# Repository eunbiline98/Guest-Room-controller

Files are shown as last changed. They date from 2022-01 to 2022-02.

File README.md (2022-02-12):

# Guest-Room-controller
dev Load Controller Guest-Room-controller Mqtt protocol home assistant support

# Guest-Room-controller V.1
- SoC board esp32
- 6 Or 8 Group Relay Omron M2YN
- Support Led Stip adressing WS2812/WS2811
- Home Assistant Integrated Or Stand Alone
# 8 Zone guest room controller
# 6 Zone guest room controller V1

# Guest-Room-controller V.2
- SoC board esp32
- 5 Group Relay SPDT 
- 3 Group Dimmer 0-10V
-  Stand Alone ( Next Home Assistant Integrated )
# guest room controller V2

# Smart Switch Momentary
https://github.com/eunbiline98/Smart-Switch-Momentary-

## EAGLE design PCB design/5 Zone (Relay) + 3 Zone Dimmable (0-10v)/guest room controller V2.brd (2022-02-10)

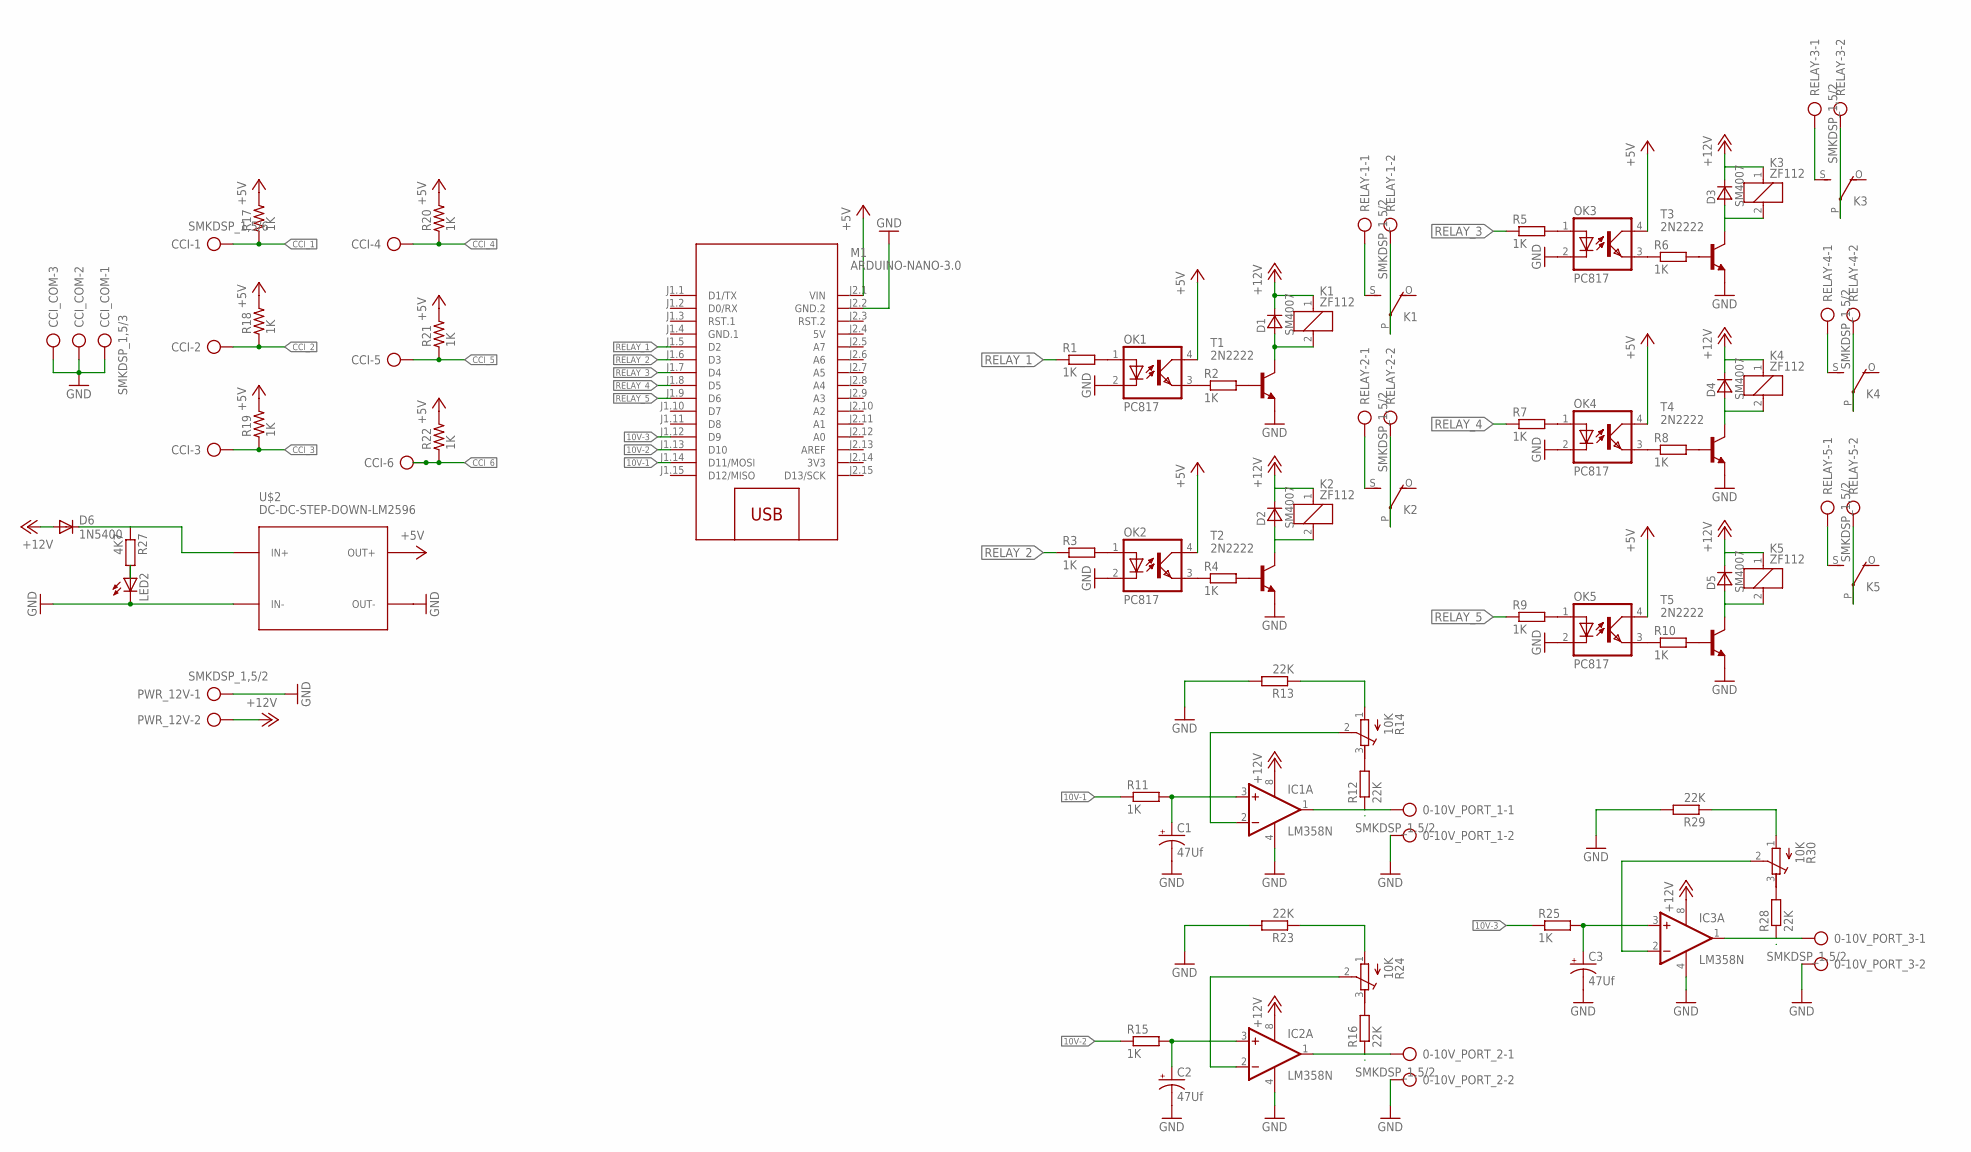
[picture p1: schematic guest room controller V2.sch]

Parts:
0-10V_PORT_1, 0-10V_PORT_2, 0-10V_PORT_3: SMKDSP_1,5/2
C1, C2, C3: 47Uf; E2,5-6
CCI: SMKDSP_1,5/6
CCI_COM: SMKDSP_1,5/3
D1, D2, D3, D4, D5: SM4007; MELF-MLL41
D6: 1N5400; DO201-15
IC1, IC2, IC3: LM358N; DIL08
K1, K2, K3, K4, K5: ZF112
LED2: LED3MM
M1: ARDUINO-NANO-3.0
OK1, OK2, OK3, OK4, OK5: PC817; DIL04
PWR_12V: SMKDSP_1,5/2
R1, R2, R3, R4, R5, R6, R7, R8, R9, R10, R11, R15, R25: 1K; 0207/10
R12, R13, R16, R23, R28, R29: 22K; 0207/10
R14, R24, R30: 10K; RTRIM64P
R17, R18, R19, R20, R21, R22: 1K; R1206
R27: 4K7; 0207/10
RELAY-1, RELAY-2, RELAY-3, RELAY-4, RELAY-5: SMKDSP_1,5/2
T1, T2, T3, T4, T5: 2N2222; TO18
U$2: DC-DC-STEP-DOWN-LM2596

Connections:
3V3: M1.J2.14 (3V3)
5V: M1.J2.4 (5V)
10V-1: M1.J1.14 (D11/MOSI), R11.1
10V-2: M1.J1.13 (D10), R15.1
10V-3: M1.J1.12 (D9), R25.1
+5V: M1.J2.1 (VIN), OK1.4 (COL), OK2.4 (COL), OK3.4 (COL), OK4.4 (COL), OK5.4 (COL), R17.2, R18.2, R19.2, R20.2, R21.2, R22.2, U$2.OUT+
+12V: D1.C, D2.C, D3.C, D4.C, D5.C, D6.A, IC1.8 (V+), IC2.8 (V+), IC3.8 (V+), K1.1, K2.1, K3.1, K4.1, K5.1, PWR_12V.2
CCI_1: CCI.1, R17.1
CCI_2: CCI.2, R18.1
CCI_3: CCI.3, R19.1
CCI_4: CCI.4, R20.1
CCI_5: CCI.5, R21.1
CCI_6: CCI.6, R22.1
GND: 0-10V_PORT_1.2, 0-10V_PORT_2.2, 0-10V_PORT_3.2, C1.-, C2.-, C3.-, CCI_COM.1, CCI_COM.2, CCI_COM.3, IC1.4 (V-), IC2.4 (V-), IC3.4 (V-), LED2.K (C), M1.J2.2 (GND.2), OK1.2 (C), OK2.2 (C), OK3.2 (C), OK4.2 (C), OK5.2 (C), PWR_12V.1, R13.2, R23.2, R29.2, T1.1 (E), T2.1 (E), T3.1 (E), T4.1 (E), T5.1 (E), U$2.IN-, U$2.OUT-
GND.1: M1.J1.4 (GND.1)
unnamed: OK1.3 (EMIT), R2.1
unnamed: R2.2, T1.2 (B)
unnamed: D1.A, K1.2, T1.3 (C)
unnamed: OK2.3 (EMIT), R4.1
unnamed: R4.2, T2.2 (B)
unnamed: D2.A, K2.2, T2.3 (C)
unnamed: OK3.3 (EMIT), R6.1
unnamed: R6.2, T3.2 (B)
unnamed: D3.A, K3.2, T3.3 (C)
unnamed: OK4.3 (EMIT), R8.1
unnamed: R8.2, T4.2 (B)
unnamed: D4.A, K4.2, T4.3 (C)
unnamed: OK5.3 (EMIT), R10.1
unnamed: R10.2, T5.2 (B)
unnamed: D5.A, K5.2, T5.3 (C)
unnamed: K1.S, RELAY-1.1
unnamed: LED2.A, R27.2
unnamed: C1.+, IC1.3 (+IN), R11.2
unnamed: 0-10V_PORT_1.1, IC1.1 (OUT), R12.1
unnamed: R12.2, R14.3 (E)
unnamed: IC1.2 (-IN), R14.2 (S)
unnamed: R13.1, R14.1 (A)
unnamed: C2.+, IC2.3 (+IN), R15.2
unnamed: OK1.1 (A), R1.2
unnamed: OK2.1 (A), R3.2
unnamed: OK3.1 (A), R5.2
unnamed: OK4.1 (A), R7.2
unnamed: OK5.1 (A), R9.2
unnamed: 0-10V_PORT_2.1, IC2.1 (OUT), R16.1
unnamed: D6.C, R27.1, U$2.IN+
unnamed: K1.P, RELAY-1.2
unnamed: R16.2, R24.3 (E)
unnamed: K2.S, RELAY-2.1
unnamed: IC2.2 (-IN), R24.2 (S)
unnamed: R23.1, R24.1 (A)
unnamed: C3.+, IC3.3 (+IN), R25.2
unnamed: 0-10V_PORT_3.1, IC3.1 (OUT), R28.1
unnamed: R28.2, R30.3 (E)
unnamed: IC3.2 (-IN), R30.2 (S)
unnamed: R29.1, R30.1 (A)
unnamed: K2.P, RELAY-2.2
unnamed: K3.S, RELAY-3.1
unnamed: K3.P, RELAY-3.2
unnamed: K4.P, RELAY-4.2
unnamed: K4.S, RELAY-4.1
unnamed: K5.P, RELAY-5.2
unnamed: K5.S, RELAY-5.1
RELAY_1: M1.J1.5 (D2), R1.1
RELAY_2: M1.J1.6 (D3), R3.1
RELAY_3: M1.J1.7 (D4), R5.1
RELAY_4: M1.J1.8 (D5), R7.1
RELAY_5: M1.J1.9 (D6), R9.1

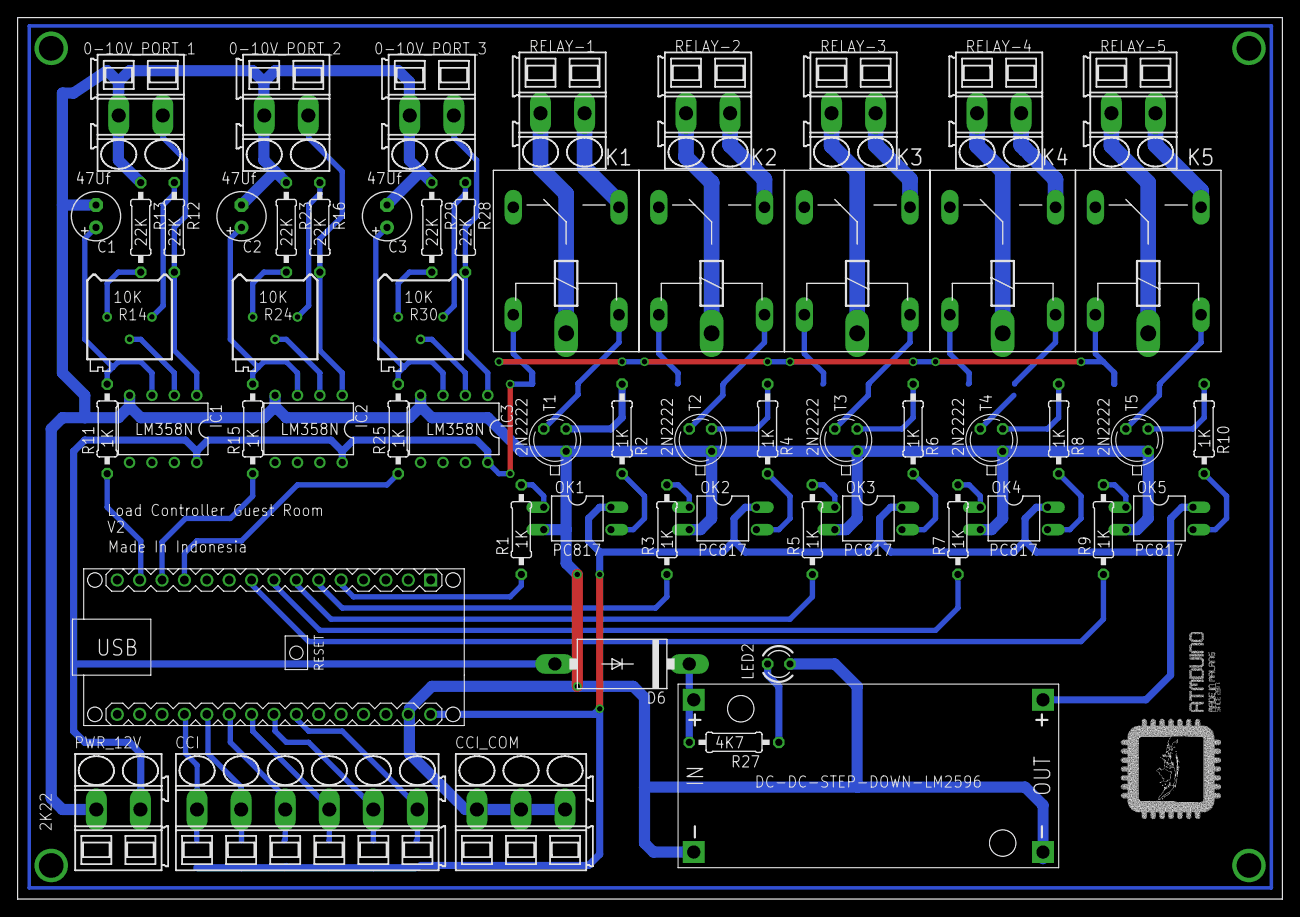
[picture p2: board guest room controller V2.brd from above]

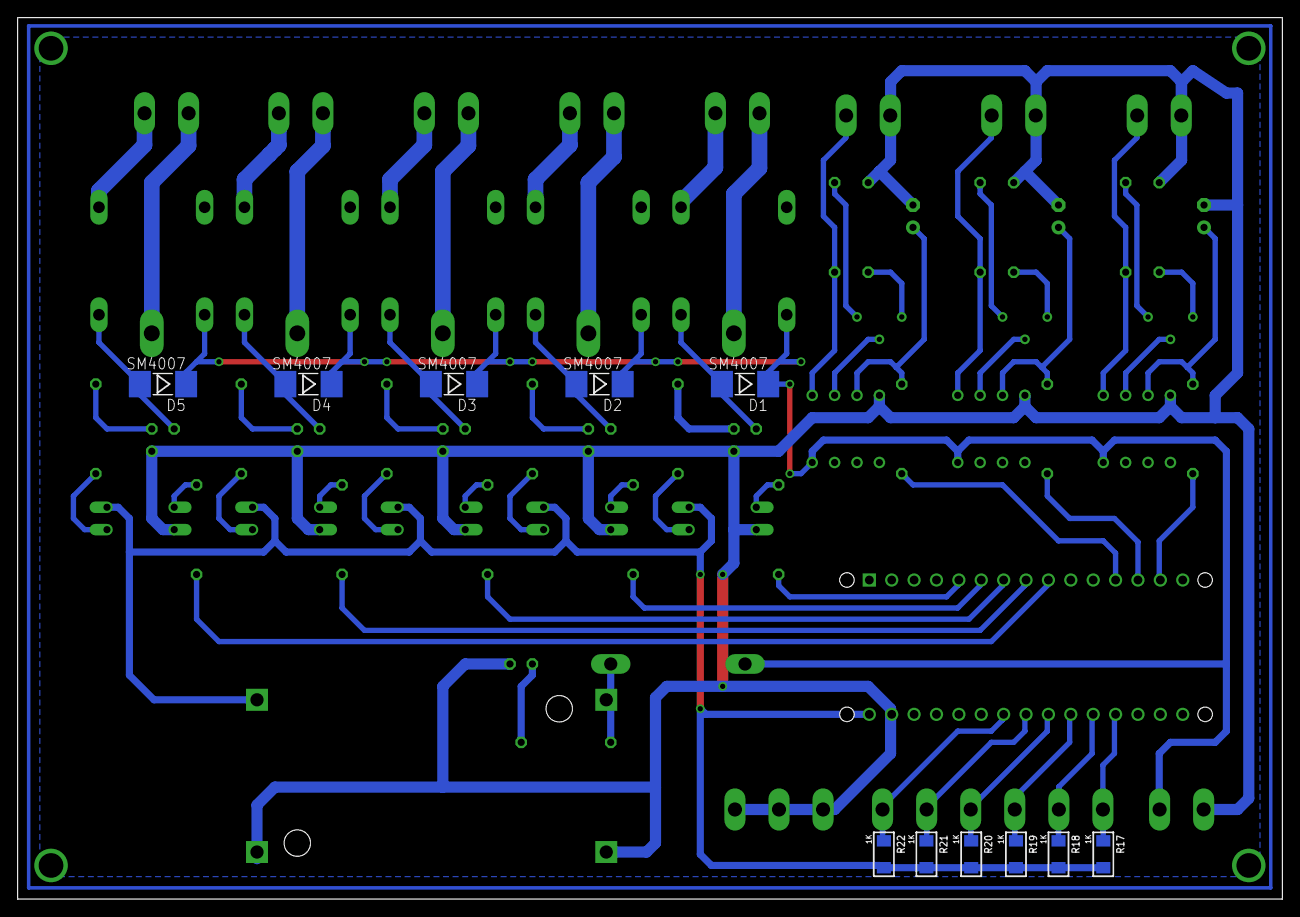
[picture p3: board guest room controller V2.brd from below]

Board: 2 copper layers, 143.5 x 100.0 mm, 70 parts (11 on the bottom side), 64 nets.

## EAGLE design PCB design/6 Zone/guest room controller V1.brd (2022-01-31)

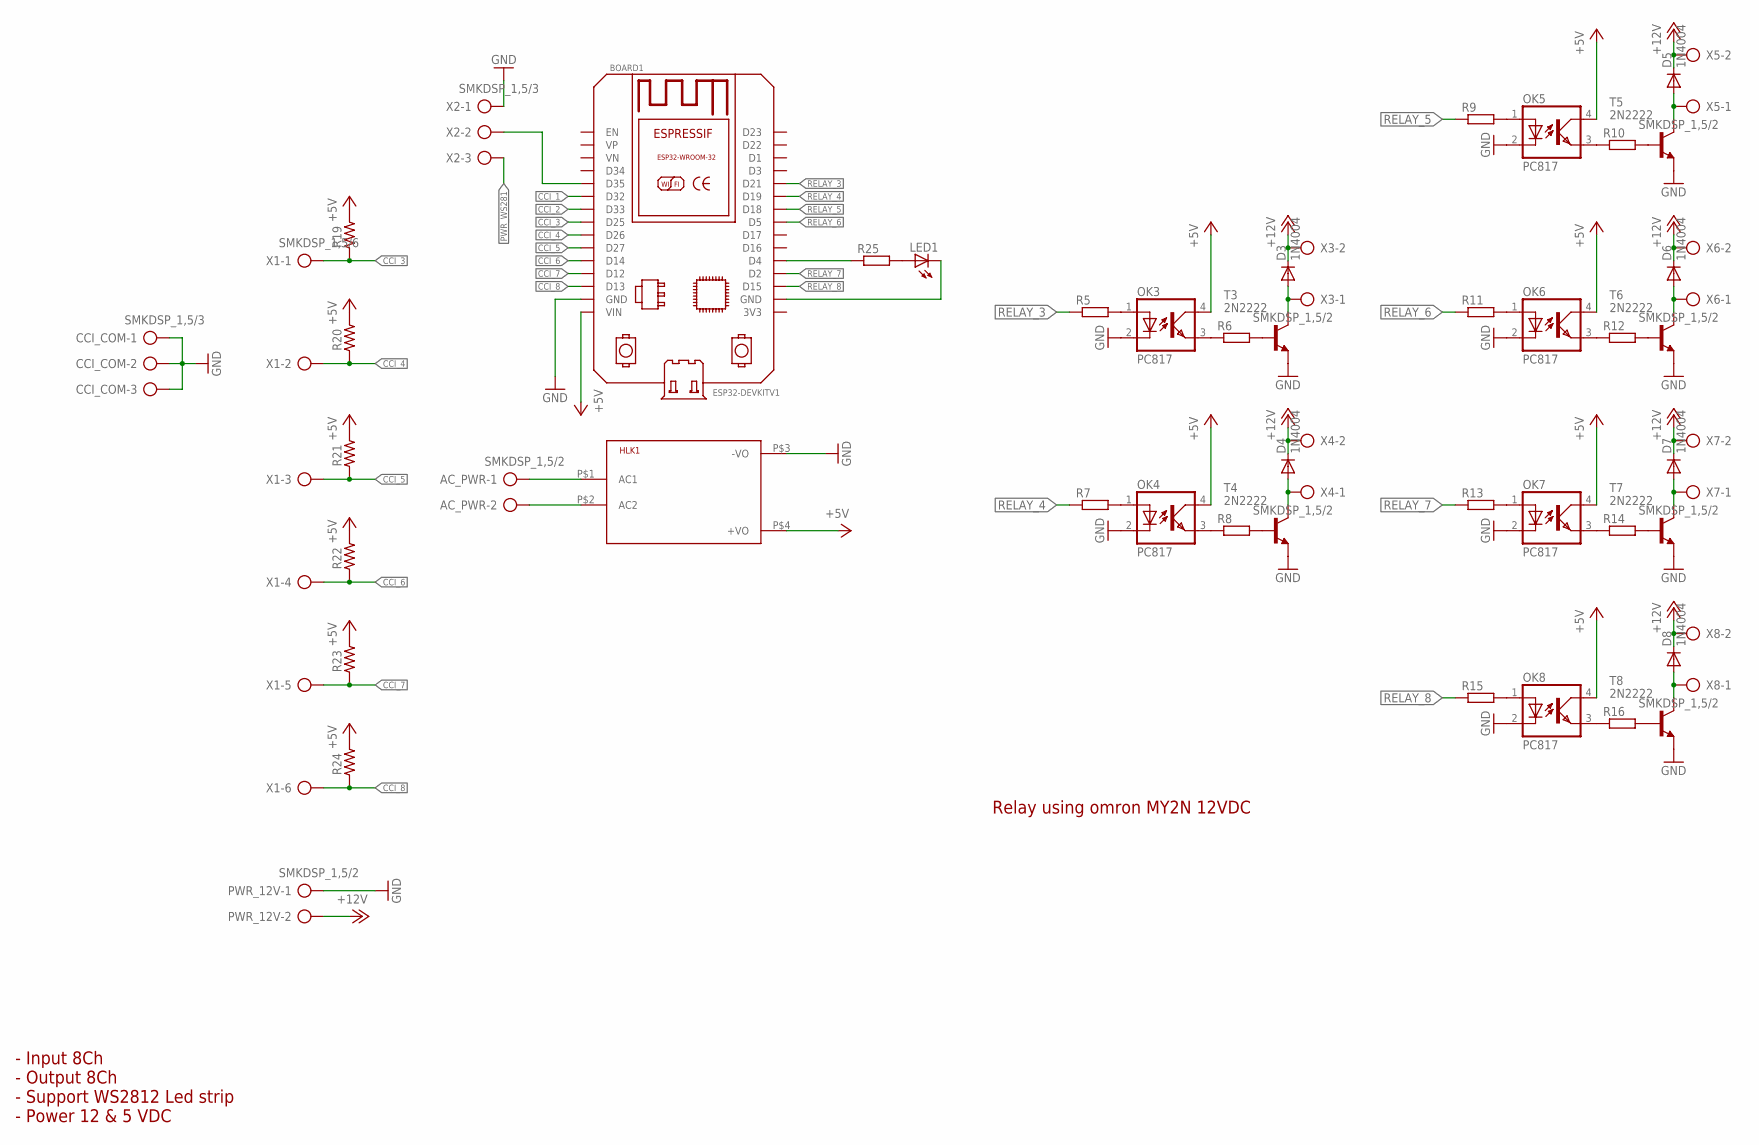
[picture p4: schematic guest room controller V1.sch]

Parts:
AC_PWR: SMKDSP_1,5/2
BOARD1: ESP32DEVKITV1; ESP32-DEVKITV1
CCI_COM: SMKDSP_1,5/3
D3, D4, D5, D6, D7, D8: 1N4004; DO41-10
HLK1: HLK-PM013W; HLK-PM01
LED1: LED3MM
OK3, OK4, OK5, OK6, OK7, OK8: PC817; DIL04
PWR_12V: SMKDSP_1,5/2
R5, R6, R7, R8, R9, R10, R11, R12, R13, R14, R15, R16, R25: R-EU_0207/10; 0207/10
R19, R20, R21, R22, R23, R24: R_1206; R1206
T3, T4, T5, T6, T7, T8: 2N2222; TO18
X1: SMKDSP_1,5/6
X2: SMKDSP_1,5/3
X3, X4, X5, X6, X7, X8: SMKDSP_1,5/2

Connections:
+5V: BOARD1.VIN, HLK1.P$4 (+VO), OK3.4 (COL), OK4.4 (COL), OK5.4 (COL), OK6.4 (COL), OK7.4 (COL), OK8.4 (COL), R19.2, R20.2, R21.2, R22.2, R23.2, R24.2
+12V: D3.C, D4.C, D5.C, D6.C, D7.C, D8.C, PWR_12V.2, X3.2, X4.2, X5.2, X6.2, X7.2, X8.2
CCI_1: BOARD1.D32
CCI_2: BOARD1.D33
CCI_3: BOARD1.D25, R19.1, X1.1
CCI_4: BOARD1.D26, R20.1, X1.2
CCI_5: BOARD1.D27, R21.1, X1.3
CCI_6: BOARD1.D14, R22.1, X1.4
CCI_7: BOARD1.D12, R23.1, X1.5
CCI_8: BOARD1.D13, R24.1, X1.6
GND: BOARD1.GND, CCI_COM.1, CCI_COM.2, CCI_COM.3, HLK1.P$3 (-VO), OK3.2 (C), OK4.2 (C), OK5.2 (C), OK6.2 (C), OK7.2 (C), OK8.2 (C), PWR_12V.1, T3.1 (E), T4.1 (E), T5.1 (E), T6.1 (E), T7.1 (E), T8.1 (E), X2.1
unnamed: OK3.3 (EMIT), R6.1
unnamed: R6.2, T3.2 (B)
unnamed: D3.A, T3.3 (C), X3.1
unnamed: OK4.3 (EMIT), R8.1
unnamed: R8.2, T4.2 (B)
unnamed: D4.A, T4.3 (C), X4.1
unnamed: OK5.3 (EMIT), R10.1
unnamed: R10.2, T5.2 (B)
unnamed: D5.A, T5.3 (C), X5.1
unnamed: OK6.3 (EMIT), R12.1
unnamed: R12.2, T6.2 (B)
unnamed: D6.A, T6.3 (C), X6.1
unnamed: OK7.3 (EMIT), R14.1
unnamed: R14.2, T7.2 (B)
unnamed: D7.A, T7.3 (C), X7.1
unnamed: OK8.3 (EMIT), R16.1
unnamed: R16.2, T8.2 (B)
unnamed: D8.A, T8.3 (C), X8.1
unnamed: AC_PWR.1, HLK1.P$1 (AC1)
unnamed: OK3.1 (A), R5.2
unnamed: OK4.1 (A), R7.2
unnamed: OK5.1 (A), R9.2
unnamed: OK6.1 (A), R11.2
unnamed: OK7.1 (A), R13.2
unnamed: OK8.1 (A), R15.2
unnamed: BOARD1.D4, R25.1
unnamed: LED1.A, R25.2
unnamed: BOARD1.GND@1 (GND), LED1.K (C)
unnamed: BOARD1.D35, X2.2
unnamed: AC_PWR.2, HLK1.P$2 (AC2)
PWR_WS281: X2.3
RELAY_3: BOARD1.D21, R5.1
RELAY_4: BOARD1.D19, R7.1
RELAY_5: BOARD1.D18, R9.1
RELAY_6: BOARD1.D5, R11.1
RELAY_7: BOARD1.D2, R13.1
RELAY_8: BOARD1.D15, R15.1

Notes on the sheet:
- Input 8Ch - Output 8Ch - Support WS2812 Led strip - Power 12 & 5 VDC
Relay using omron MY2N 12VDC

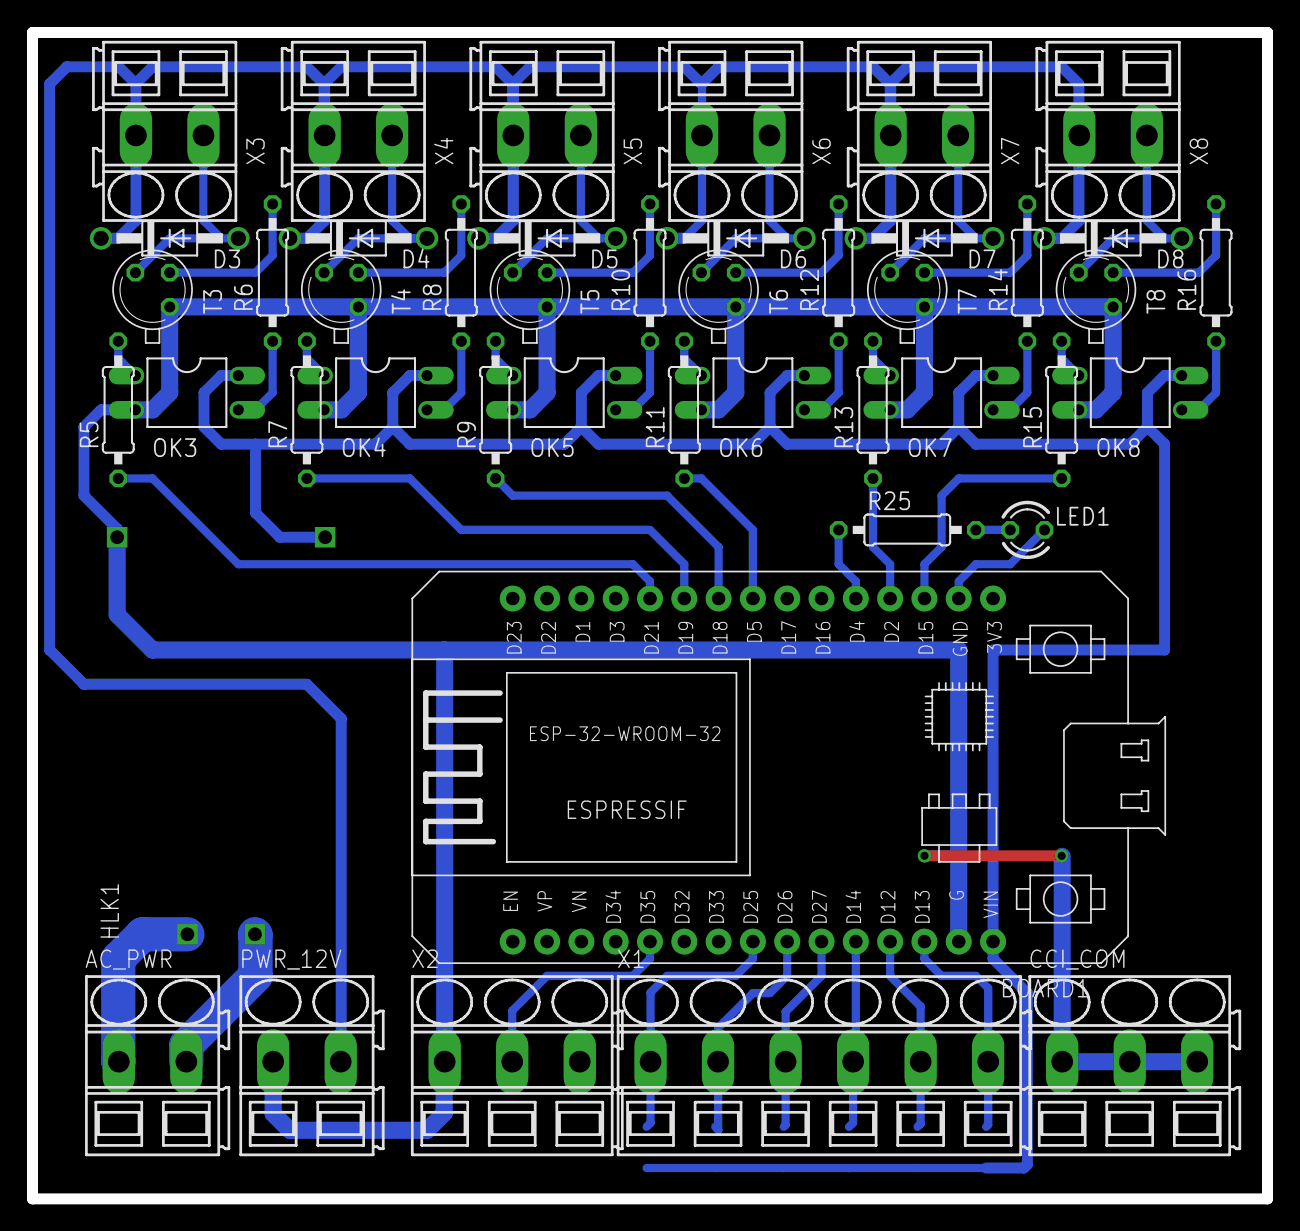
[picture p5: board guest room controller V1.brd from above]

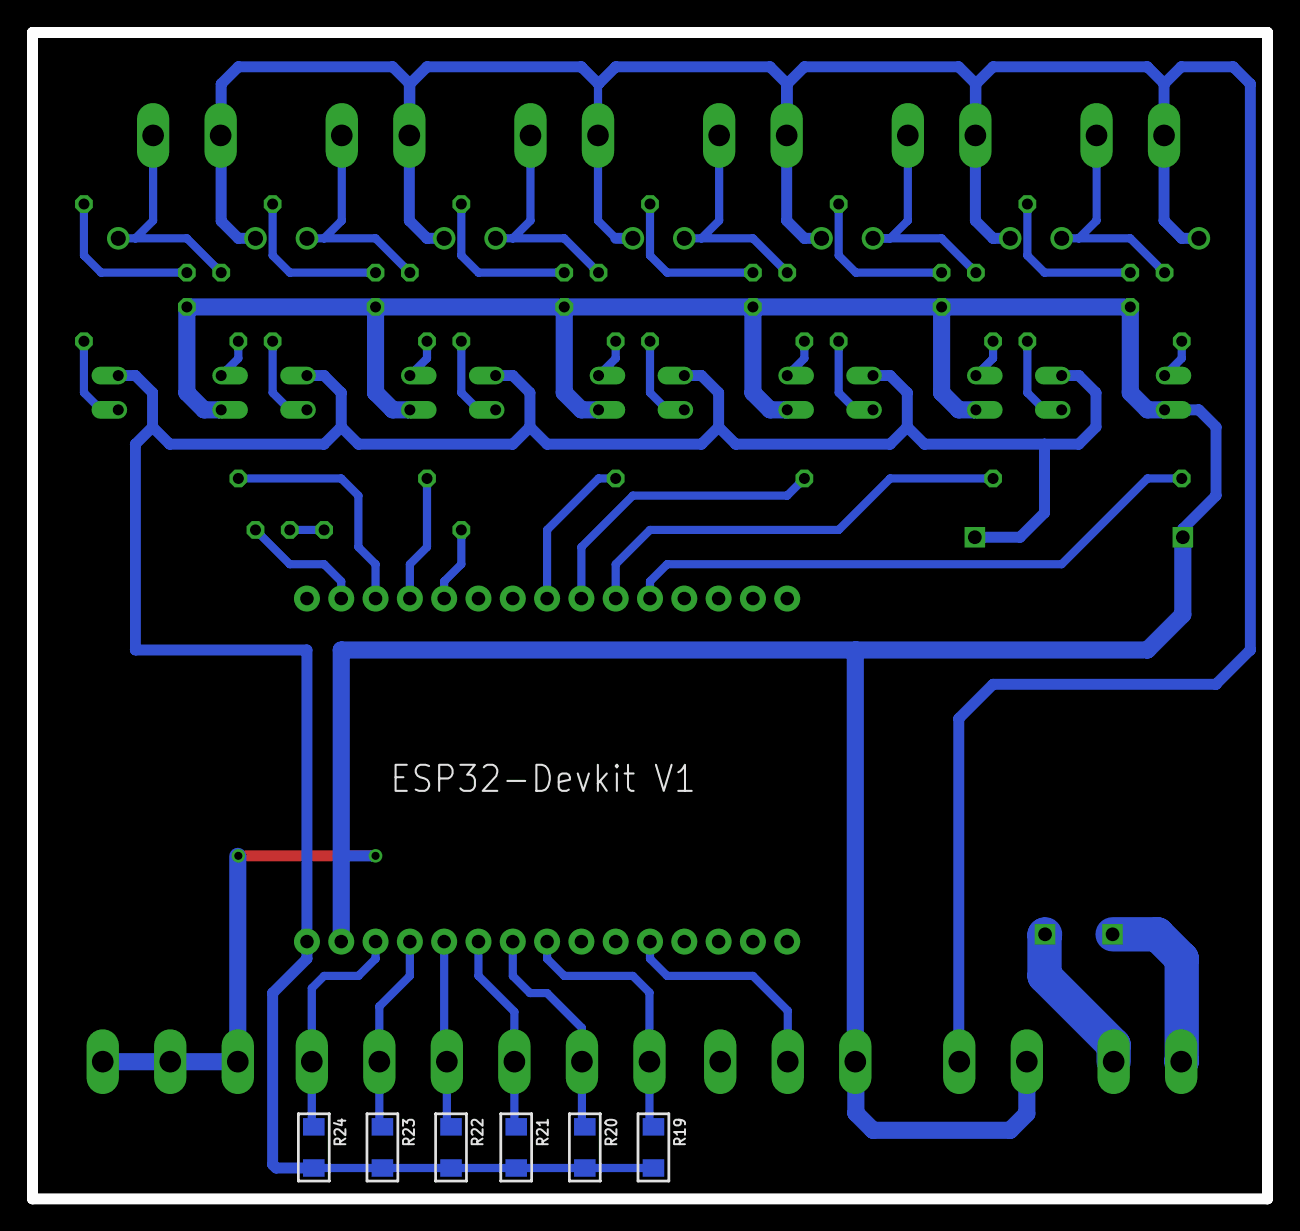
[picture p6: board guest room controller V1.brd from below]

Board: 2 copper layers, 91.4 x 86.4 mm, 51 parts (6 on the bottom side), 45 nets.

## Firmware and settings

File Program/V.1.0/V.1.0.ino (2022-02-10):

#include <WiFi.h>
#include <PubSubClient.h>

const char *ssid = "Kost Pak Josa";
const char *password = "joputra1";
const char *MQTT_SERVER = "192.168.1.21";

const char *MQTT_TOPIC1 = "relay/1/state";
const char *MQTT_TOPIC2 = "relay/2/state";
const char *MQTT_TOPIC3 = "relay/3/state";
const char *MQTT_TOPIC4 = "relay/4/state";
const char *MQTT_TOPIC5 = "relay/5/state";
const char *MQTT_TOPIC6 = "relay/6/state";
const char *MQTT_TOPIC7 = "relay/7/state";
const char *MQTT_TOPIC8 = "relay/8/state";

const char *R1 = "relay/1/cmd";
const char *R2 = "relay/2/cmd";
const char *R3 = "relay/3/cmd";
const char *R4 = "relay/4/cmd";
const char *R5 = "relay/5/cmd";
const char *R6 = "relay/6/cmd";
const char *R7 = "relay/7/cmd";
const char *R8 = "relay/8/cmd";

const char *MQTT_CLIENT_ID = "guest_room_1";
const char *MQTT_USERNAME = "admin";
const char *MQTT_PASSWORD = "admin";

WiFiClient espClient;
PubSubClient client(espClient);

// Pin Setup
#define relay_1 15
#define relay_2 12
#define relay_3 5
#define relay_4 18
#define relay_5 19
#define relay_6 21
#define relay_7 22
#define relay_8 23

#define keyCard 13
#define btn_1 12
#define btn_2 14
#define btn_3 27
#define btn_4 26
#define btn_5 25

int lastMilis = 0;
unsigned long nowMillis = millis();

void setup_wifi()
{
  // Connect to Wifi Network
  pinMode(4, OUTPUT); // WiFi Indicator
  Serial.println();
  Serial.print("Connecting to ");
  Serial.println(ssid);

  WiFi.begin(ssid, password);

  while (WiFi.status() != WL_CONNECTED)
  {
    digitalWrite(4, HIGH);
    delay(80);
    digitalWrite(4, LOW);
    delay(80);
  }

  Serial.println("");
  Serial.println("WiFi connected");
  Serial.println("IP address: ");
  Serial.println(WiFi.localIP());
}

void callback(char *topic, byte *message, unsigned int length)
{
  Serial.print("Message arrived in topic: ");
  Serial.println(topic);
  Serial.print("Message:");
  String messageTemp;

  for (int i = 0; i < length; i++)
  {
    Serial.print((char)message[i]);
    Serial.println();
    if ((char)message[i] != '"')
      messageTemp += (char)message[i];
  }

  if (String(topic) == R1)
  {
    if (messageTemp == "1")
    {
      digitalWrite(relay_1, HIGH);
      client.publish(MQTT_TOPIC1, "1");
    }
    else if (messageTemp == "0")
    {
      digitalWrite(relay_1, LOW);
       client.publish(MQTT_TOPIC1,"0");
    }
  }

  if (String(topic) == R2)
  {
    if (messageTemp == "1")
    {
      digitalWrite(relay_2, HIGH);
      client.publish(MQTT_TOPIC2,"1");
    }
    else if (messageTemp == "0")
    {
      digitalWrite(relay_2, LOW);
      client.publish(MQTT_TOPIC2,"0");
    }
  }

  if (String(topic) == R3)
  {
    if (messageTemp == "1")
    {
      digitalWrite(relay_3, HIGH);
      client.publish(MQTT_TOPIC3,"1");
    }
    else if (messageTemp == "0")
    {
      digitalWrite(relay_3, LOW);
      client.publish(MQTT_TOPIC3,"0");
    }
  }

  if (String(topic) == R4)
  {
    if (messageTemp == "1")
    {
      digitalWrite(relay_4, HIGH);
      client.publish(MQTT_TOPIC4,"1");
    }
    else if (messageTemp == "0")
    {
      digitalWrite(relay_4, LOW);
      client.publish(MQTT_TOPIC4,"0");
    }
  }

  if (String(topic) == R5)
  {
    if (messageTemp == "1")
    {
      digitalWrite(relay_5, HIGH);
      client.publish(MQTT_TOPIC5,"1");
    }
    else if (messageTemp == "0")
    {
      digitalWrite(relay_5, LOW);
      client.publish(MQTT_TOPIC5,"0");
    }
  }

  if (String(topic) == R6)
  {
    if (messageTemp == "1")
    {
      digitalWrite(relay_6, HIGH);
      client.publish(MQTT_TOPIC6,"1");
    }
    else if (messageTemp == "0")
    {
      digitalWrite(relay_6, LOW);
      client.publish(MQTT_TOPIC6,"0");
    }
  }

  if (String(topic) == R7)
  {
    if (messageTemp == "1")
    {
      digitalWrite(relay_7, HIGH);
      client.publish(MQTT_TOPIC7,"1");
    }
    else if (messageTemp == "0")
    {
      digitalWrite(relay_7, LOW);
      client.publish(MQTT_TOPIC7,"0");
    }
  }

  if (String(topic) == R8)
  {
    if (messageTemp == "1")
    {
      digitalWrite(relay_8, HIGH);
      client.publish(MQTT_TOPIC8,"1");
    }
    else if (messageTemp == "0")
    {
      digitalWrite(relay_8, LOW);
      client.publish(MQTT_TOPIC8,"0");
    }
  }
}

void reconnect()
{
  // Loop until we're reconnected
  while (!client.connected())
  {
    Serial.print("Attempting MQTT connection...");
    // Attempt to connect
    if (client.connect(MQTT_CLIENT_ID, MQTT_USERNAME, MQTT_PASSWORD))
    {
      Serial.println("connected");
      // subscribe
      client.subscribe(R1);
      client.subscribe(R2);
      client.subscribe(R3);
      client.subscribe(R4);
      client.subscribe(R5);
      client.subscribe(R6);
      client.subscribe(R7);
      client.subscribe(R8);
    }
    else
    {
      Serial.print("failed, rc=");
      Serial.print(client.state());
      Serial.println(" try again in 5 seconds");
      // Wait 5 seconds before retrying
      delay(5000);
    }
  }
}

void setup()
{
  // Serial port for debugging purposes
  Serial.begin(115200);
  setup_wifi();

  // MQTT Server Setup
  client.setServer(MQTT_SERVER, 1883);
  client.setCallback(callback);

  pinMode(4, OUTPUT); // WiFi Indicator
  pinMode(relay_1, OUTPUT);
  pinMode(relay_2, OUTPUT);
  pinMode(relay_3, OUTPUT);
  pinMode(relay_4, OUTPUT);
  pinMode(relay_5, OUTPUT);
  pinMode(relay_6, OUTPUT);
  pinMode(relay_7, OUTPUT);
  pinMode(relay_8, OUTPUT);

  pinMode(btn_1, INPUT);
  pinMode(btn_2, INPUT);
  pinMode(btn_3, INPUT);
  pinMode(btn_4, INPUT);
  pinMode(btn_5, INPUT);
  pinMode(keyCard, INPUT);
}

void loop()
{
  if (!client.connected())
  {
    reconnect();
  }
  client.loop();
}

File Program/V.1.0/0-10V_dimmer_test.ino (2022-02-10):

#include <TM1637Display.h>

#define CLK 3
#define DIO 2

int upDim = 4;
int downDim = 5;
int upVal;
int downVal;
int pwmout = 9;
int bright = 17;
int fade = 150;

int percent = 0;

unsigned int angka = 0;
TM1637Display display(CLK, DIO);

void setup()
{
  display.setBrightness(0x0f);
  pinMode(upDim, INPUT_PULLUP);
  pinMode(downDim, INPUT_PULLUP);
  pinMode(pwmout, OUTPUT);
  Serial.begin(9600);
}

void loop()
{
  int val = 1;
  upVal = digitalRead(upDim);
  downVal = digitalRead(downDim);
  delay(fade);
  if (upVal == 0)
  {
    bright = bright + val;
  }
  if (downVal == 0)
  {
    bright = bright - val;
  }
  if (bright > 255)
  {
    bright = 255;
  }
  if (bright < 0)
  {
    bright = 0;
  }

  percent = ((bright / 255.00) * 100);

  analogWrite(pwmout, bright);
  Serial.print("percentage = ");
  Serial.print(percent);
  Serial.println("%\n\n");
  display.showNumberDec(percent);
}

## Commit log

2022-01-31 adding PCB design V.1
    [guest room controller V1.brd, guest room controller V1.sch, guest room controller.brd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]
2022-02-10 Adding Program Test Module 0-10V
2022-02-10 Adding PCB Design
    [guest room controller V2.brd, guest room controller V2.sch]
2022-02-10 Adding File Gerber

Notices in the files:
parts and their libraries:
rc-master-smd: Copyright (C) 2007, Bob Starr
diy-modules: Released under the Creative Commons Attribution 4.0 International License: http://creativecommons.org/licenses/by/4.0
